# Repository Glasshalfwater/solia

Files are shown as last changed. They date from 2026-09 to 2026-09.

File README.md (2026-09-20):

# solia
### A compact tamagotchi in a rectangular form factor:

This originally started off as an idea for a birthday gift, however I realized that the timeline in which I had hoped to accomplish it was quite unrealistic. It also served as a fun way to learn KiCad (my previous projects were designed in EasyEDA Pro). The actual tamagotchi guided project took maybe 3-4 days to finish, but I wanted to make it, frankly, cooler. I decided to add a full-color TFT display, Kailh Choc keys for a more satisfying user experience, and a LiPO battery (of course along with temperature monitoring, fuse, etc.) for improved battery life. Soooo, it's been about a month and a half since I started this, said person's birthday passed a month ago, but hopefully it will be finally built soon. Another reason why I wanted to build something more complex than a basic tamagotchi (other than making it more interesting as a gift) was so it would be more fun to update later down the line. I could create "DLCs" or expansions to serve as further iterations or updates. (I had wanted to make a full color tamagotchi, so I was thinking of continuously adding new creatures with better graphics.)

### Images:

Wiring Schematic:
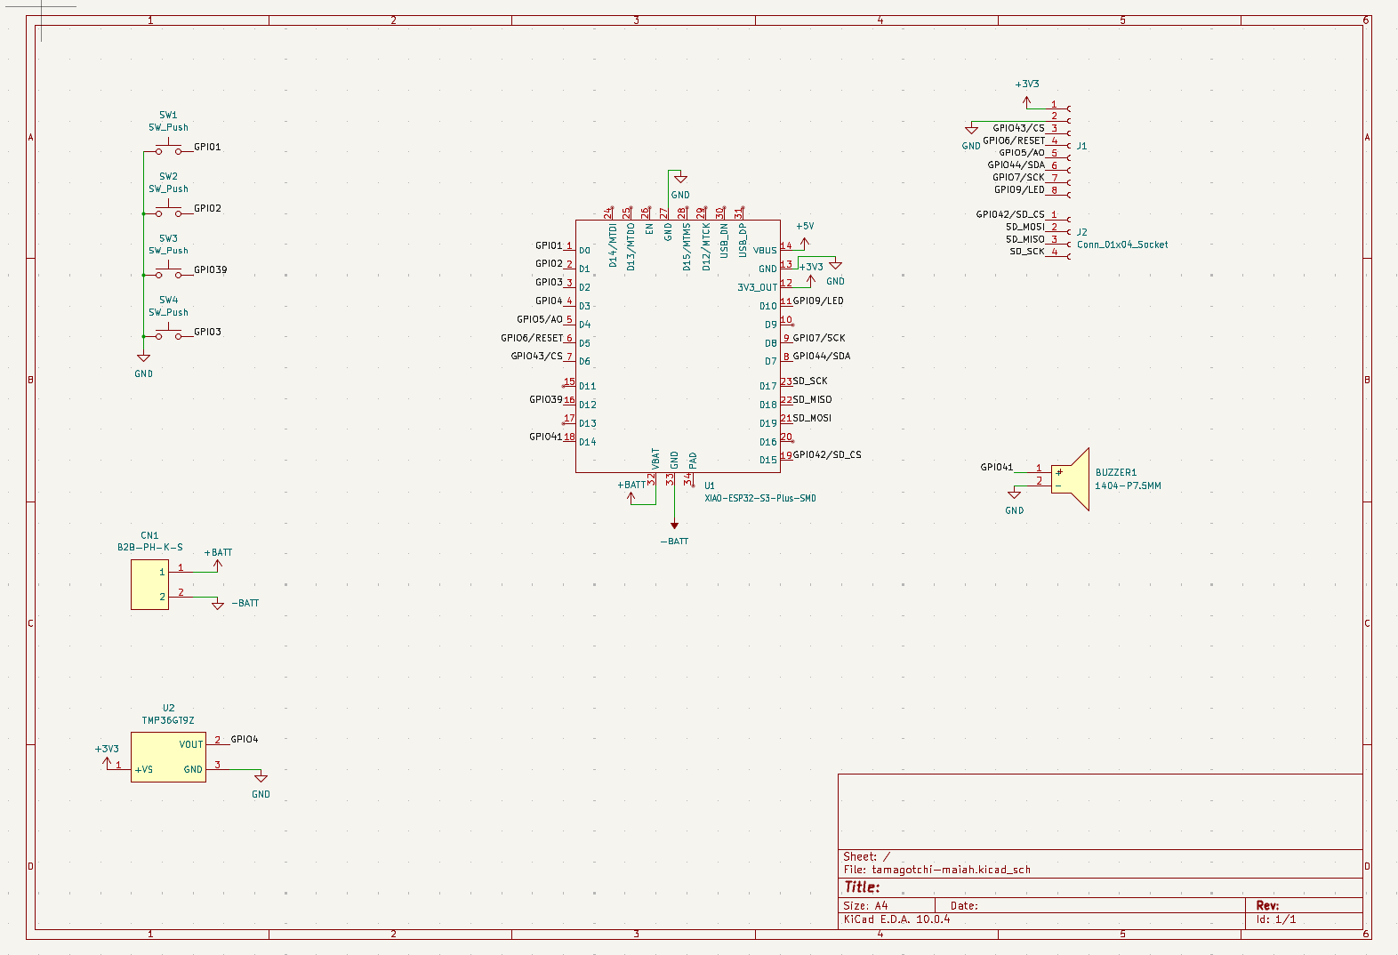
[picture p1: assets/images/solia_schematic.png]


PCB Bottom Layer:
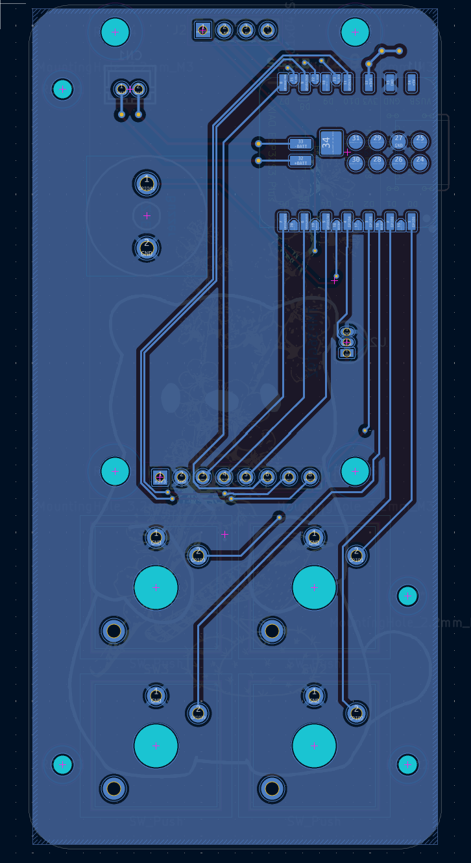
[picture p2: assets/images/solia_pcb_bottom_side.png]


PCB Top Layer:
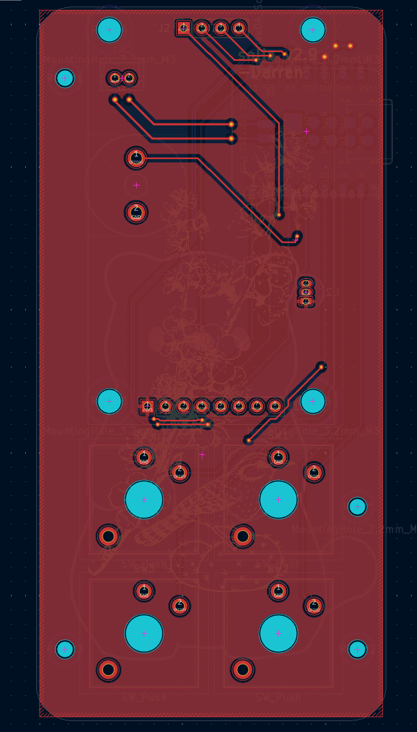
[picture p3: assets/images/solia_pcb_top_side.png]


PCB Bottom View:
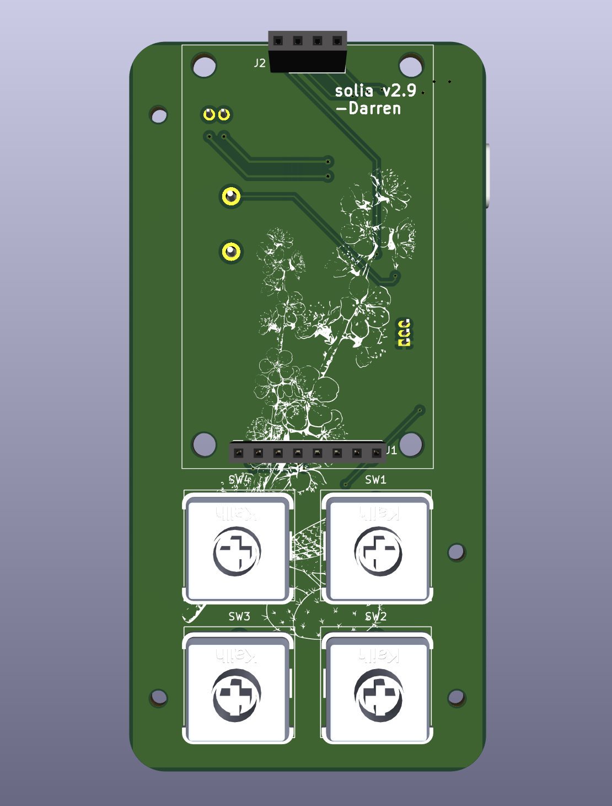
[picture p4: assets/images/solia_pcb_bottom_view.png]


PCB Top View:
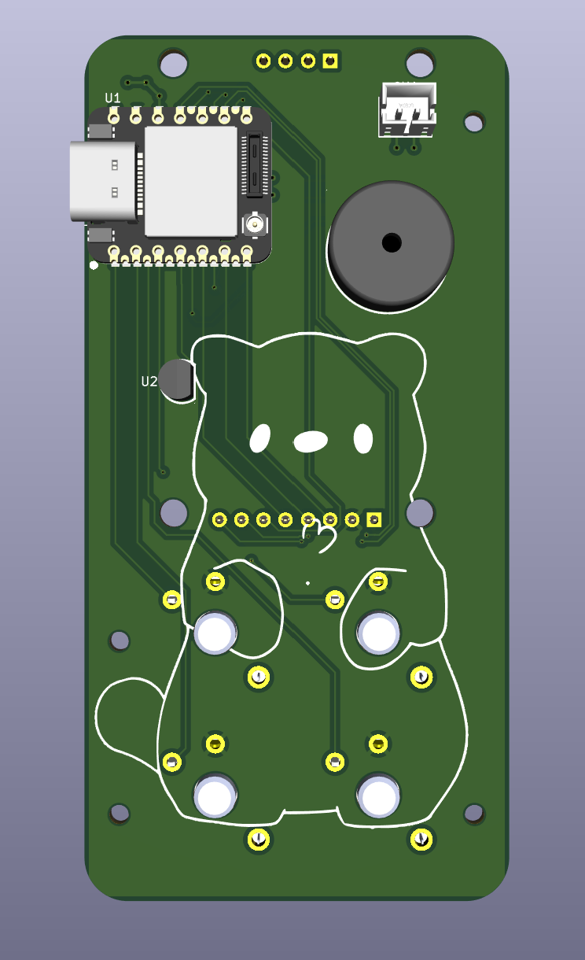
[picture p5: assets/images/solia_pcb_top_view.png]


Assembly Isometric View:
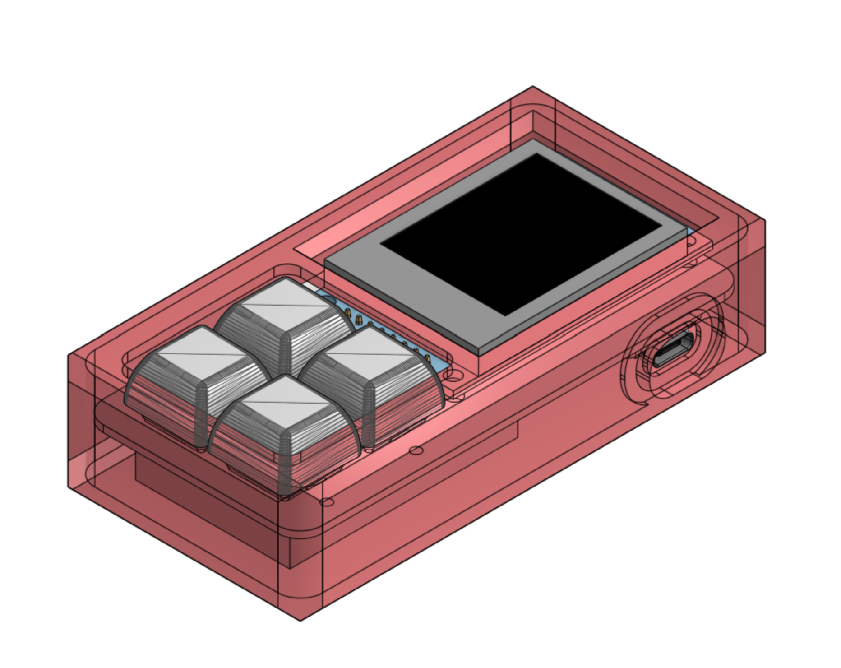
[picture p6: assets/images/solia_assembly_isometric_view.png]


Assembly Top View:
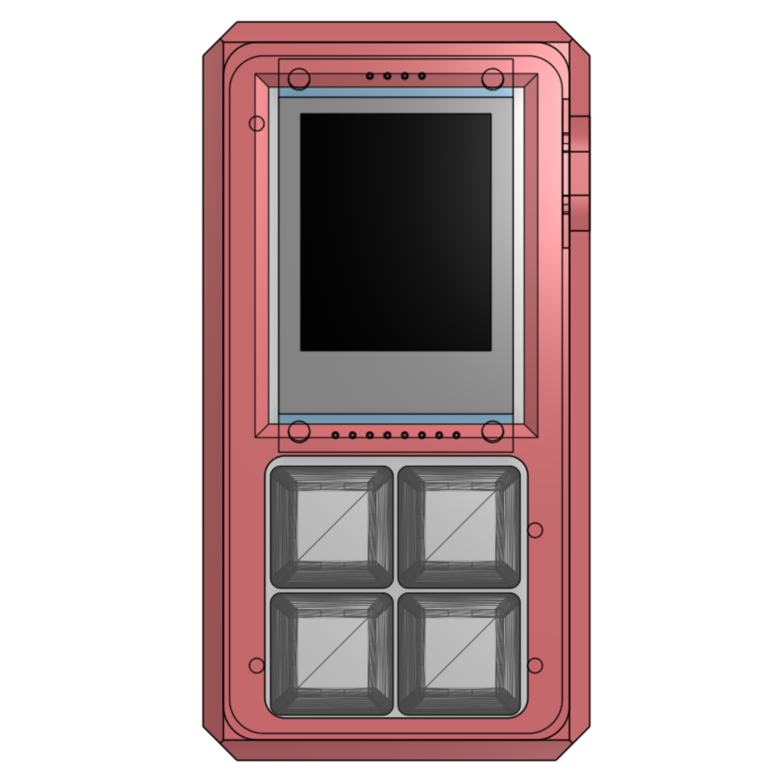
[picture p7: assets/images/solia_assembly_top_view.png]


Assembly Bottom View:
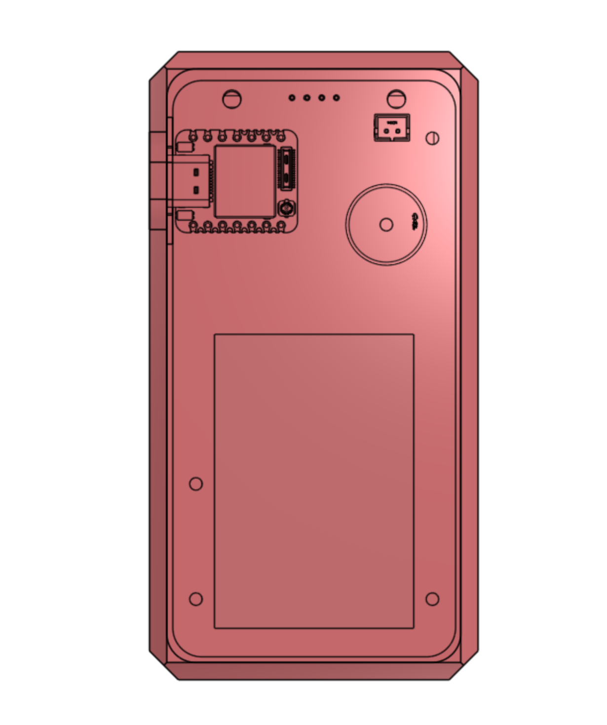
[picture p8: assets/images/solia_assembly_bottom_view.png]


Assembly Side View:
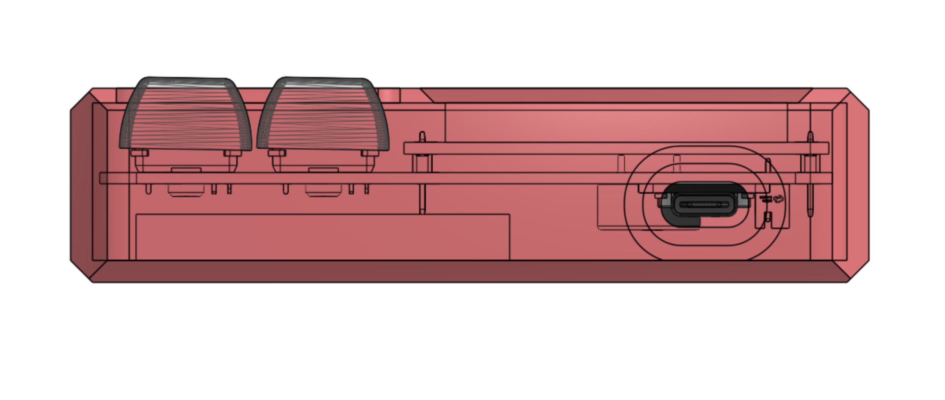
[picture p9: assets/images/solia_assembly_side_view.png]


### Onshape Link:
[Onshape Document :D](https://cvilleschools.onshape.com/documents/4abba4c252e7ebcaf10d09a4/w/88913430d3dbe53bf4207c72/e/fed4882613c54d204ad1a2a2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) 
 
### Component List:
|Name |Quantity |Price |Link |FIELD5|
|---|---|---|---|---|
|Total | N/A | ~85-90 (<65 for components but + tax and shipping and depends on how expensive your shipping is)| N/A | |
|PCB Boards | 5 (min quantity from JLCPCBD) | ~$7.00 w/ shipping | jlcpcb.com | |
|Seeed Studio XIAO ESP32 S3 Plus | 1 | $7.99 | https://www.seeedstudio.com/Seeed-Studio-XIAO-ESP32S3-Plus-p-6361.html | |
|Kailh Choc v2 Low Profile Keyboard Switches (brown switch variety)  | 10 (need 4 but whatever min quantity you can find)| $12.00 | https://www.amazon.com/KAILH-Profile-Mechanical-Keyboard-Keystem/dp/B0B463YXGQ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 | |
|Cherry MX Style Blank Keycaps 1U (white - 18 x 18 mm) | 10 (need 4) | ~$10 (for ten) | https://www.amazon.com/PATIKIL-Universal-Replacement-Accessories-Mechanical/dp/B0B5KZQ9X9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 | |
|1.8" TFT LCD Display | 1 | $14.99 | https://shillehtek.com/products/shillehtek-1-8-inch-tft-lcd-display-module-dual-side-soldering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 | |
|3.7v 1100 mAh Lithium Polymer Battery (2pin JST-PH 2.0 mm connector)| 1 | ~11 | https://www.amazon.com/EEMB-1100mAh-Battery-Rechargeable-Connector/dp/B08FD39Y5R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| |
|Temperature Sensor | 1 | $2.78 | https://www.lcsc.com/product-detail/Temperature-Sensors_ADI_TMP36GT9Z_TMP36GT9Z_C53490.html | |
|Passive Piezo-Electric Buzzer | 10 (min purchase amount for this specific model)  | $0.75 (for ten) | https://www.lcsc.com/product-detail/C49246966.html?s_z=n_q_C49246966&globalKeyword=C49246966 | |

### Setup Instructions:
Once your PCBs, case, and components arrive (list of used components), attach the XIAO via USB-C data cable to a computer capable of flashing firmware. There are multiple ways of doing so, but given that the firmware is already a .ino file, one could simply install Arduino IDE and use the built in flashing tool (just google Arduino IDE install and docs). Afterwards, assemble the PCB components, where you will likely need a hot plate for the XIAO board. Or, if you didn't screw up like me, I highly recommend editing the PCB files to include holes underneat the XIAO battery pads, so you don't have to only use solder paste and hope (if you're editing the PCB, I also recommend swapping the placement of the buzzer and the XIAO, as I didn't realize that the pins from the buzzer would hit the SD card slot attached to the screen). There is a very specific order to which the components need not to be assembled, but essentially just solder the XIAO first and confirm that nothing is shorted (multimeter, etc.), then the buzzer and temperature sensor, then the keys, and lastly the screen (as long as the XIAO is first and the screen is left to last it should be fine). Afterwards, solder the temperature fuse in between one of the battery wires (I chose positive) and the female JST connector on the board and tape the fuse onto the battery's back (adjust the postition so it slots into the hole in the case). Once you've assembled everything onto the board, place foam around the bottom of the case except for in the cutout for the fuse, and nestle the battery in. Plug the battery into the board, place everything in and seal the top of the case, and you should be good to go!
# solia_firmware

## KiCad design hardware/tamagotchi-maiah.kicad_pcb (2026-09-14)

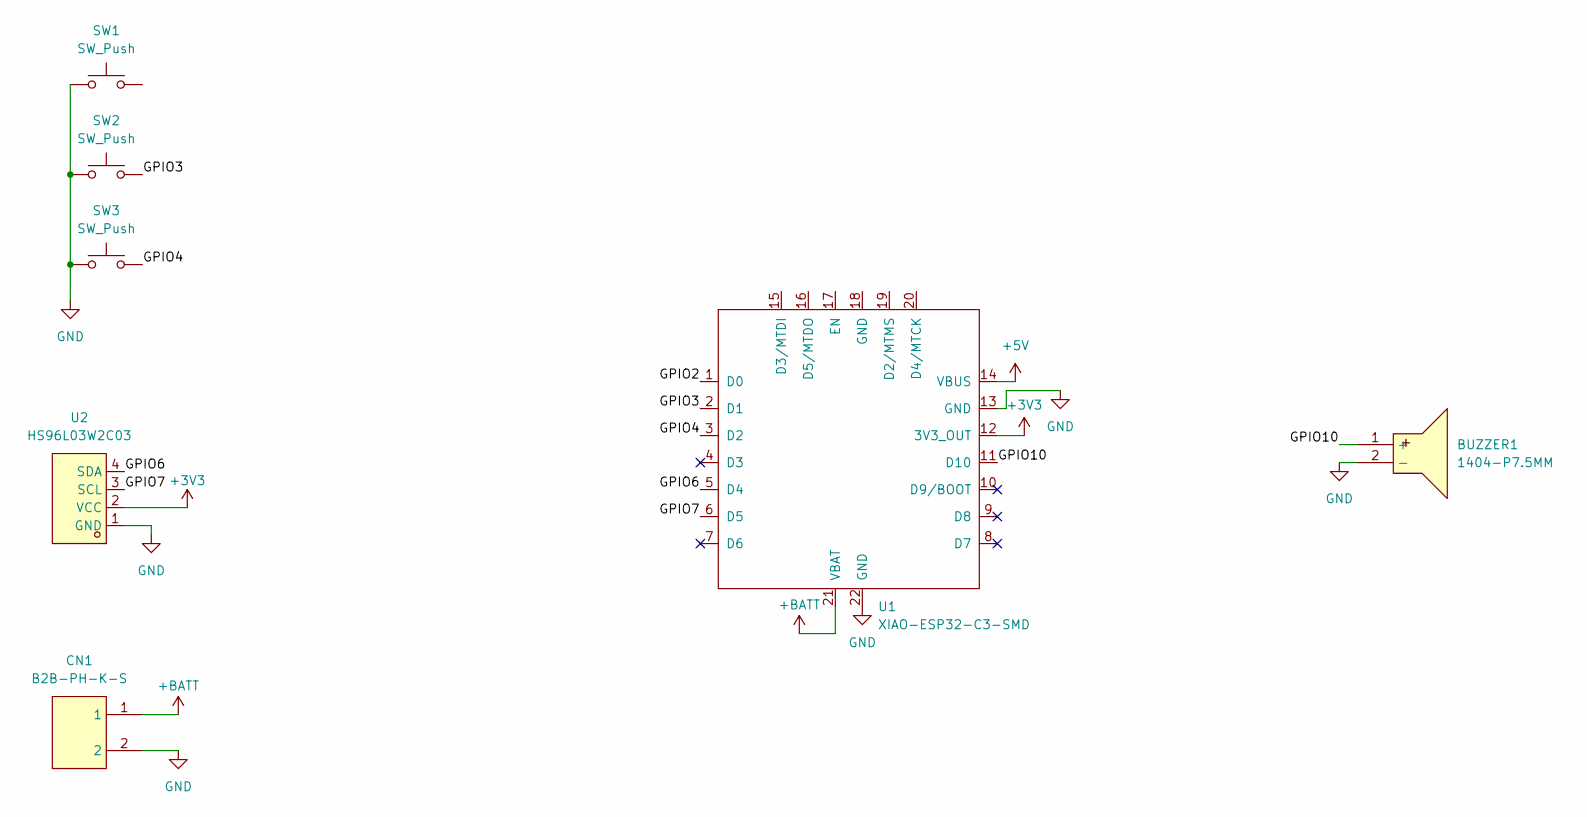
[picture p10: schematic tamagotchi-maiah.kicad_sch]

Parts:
BUZZER1: 1404-P7.5MM; BUZ-TH_BD14.0-P7.60-D0.8-L; MPN 1404-P7.5MM; LCSC Part C49246966
CN1: B2B-PH-K-S; CONN-TH_B2B-PH-K-S; MPN B2B-PH-K-S(LF)(SN); LCSC Part C131337
SW1, SW2, SW3: SW_Push; SW-TH_4P-L4.5-W4.5-P3.00-LS4.8
U1: XIAO-ESP32-C3-SMD
U2: HS96L03W2C03; OLED-TH_L27.8-W27.2-P2.54_C9900033791; MPN HS96L03W2C03; LCSC Part C5248080

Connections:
+3V3: U1.12 (3V3_OUT), U2.2 (VCC)
+5V: U1.14 (VBUS)
+BATT: CN1.1, U1.21 (VBAT)
/GPIO2: SW1.2, U1.1 (D0)
/GPIO3: SW2.2, U1.2 (D1)
/GPIO4: SW3.2, U1.3 (D2)
/GPIO6: U1.5 (D4), U2.4 (SDA)
/GPIO7: U1.6 (D5), U2.3 (SCL)
/GPIO10: BUZZER1.1 (+), U1.11 (D10)
GND: BUZZER1.2 (-), CN1.2, SW1.1, SW2.1, SW3.1, U1.13 (GND), U1.22 (GND), U2.1 (GND)

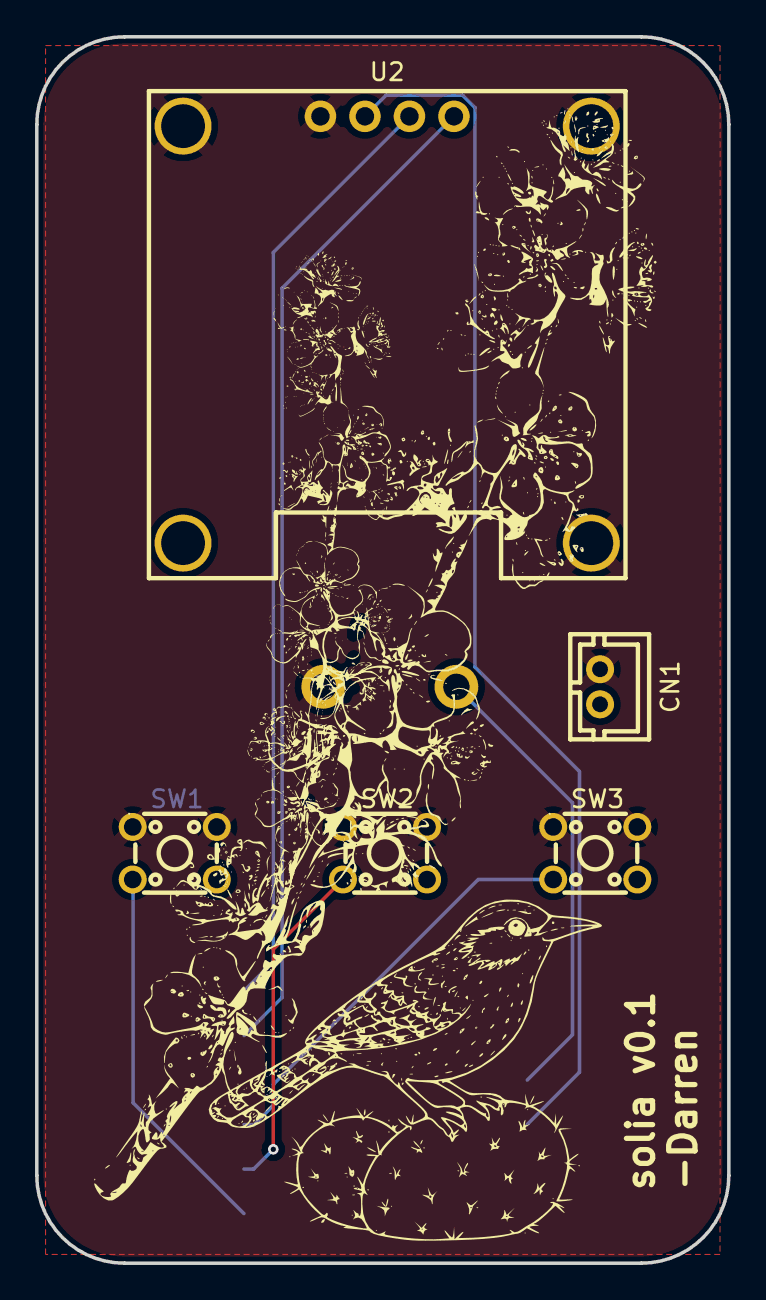
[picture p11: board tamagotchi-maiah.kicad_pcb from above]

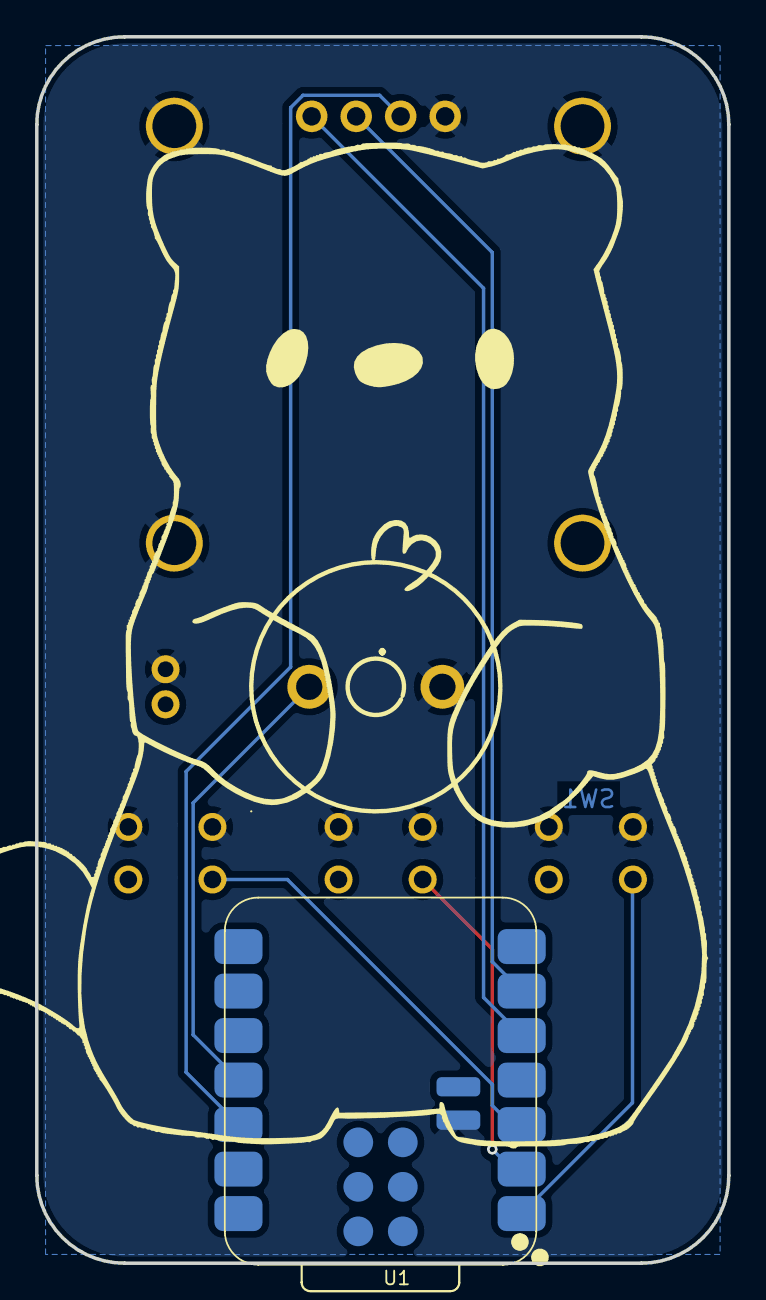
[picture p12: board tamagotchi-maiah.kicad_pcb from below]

Board: 2 copper layers, 39.5 x 70.0 mm, 8 parts (3 on the bottom side), 9 nets.

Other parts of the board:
.: LOGO; soup_on_silkscreen(50x58.2)

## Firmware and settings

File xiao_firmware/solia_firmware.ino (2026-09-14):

#include "lib\TFT_eSPI\TFT_eSPI.h"
#include "lib\TFT_eSPI\User_Setup.h" 

const int BTN_TR =  1;
const int BTN_TL = 2;
const int BTN_BL = 39;
const int BTN_BR = 3;

unsigned long last_button_press = 0;

const int TMP_SENSOR = 4;
 
const int BUZZER_PIN = 41;

TFT_eSPI tft = TFT_eSPI();

struct Pet 
{
  // Range from 0 to 100 with 0 being the lowest and 100 being the best
  int hunger;
  int happiness;
  int energy;
  unsigned long age;
};

Pet fox;

unsigned long last_update = 0;
unsigned long pet_starving = 0;
unsigned long pet_depressed = 0;
unsigned long pet_exhausted = 0;


enum Screen
{
  SCREEN_MAIN,
  SCREEN_FEED,
  SCREEN_PLAY,
  SCREEN_SLEEP,

};


Screen current_screen = SCREEN_MAIN;
Screen screen_array[] = {SCREEN_MAIN, SCREEN_FEED, SCREEN_PLAY, SCREEN_SLEEP};
int screen_index = 0;
// Example: happy face (all stats above 50)
const unsigned char PROGMEM petHappy[] = {
  0b00000000, 0b00000000,
  0b00011111, 0b11111000,
  0b00100000, 0b00000100,
  0b01000000, 0b00000010,
  0b01001100, 0b00110010,
  0b01001100, 0b00110010,
  0b01000000, 0b00000010,
  0b01000000, 0b00000010,
  0b01000100, 0b00100010,
  0b01000011, 0b11000010,
  0b01000000, 0b00000010,
  0b00100000, 0b00000100,
  0b00011111, 0b11111000,
  0b00000000, 0b00000000,
  0b00000000, 0b00000000,
  0b00000000, 0b00000000
};

// Example: sad face (any stat below 30)
const unsigned char PROGMEM petSad[] = {
  0b00000000, 0b00000000,
  0b00011111, 0b11111000,
  0b00100000, 0b00000100,
  0b01000000, 0b00000010,
  0b01001100, 0b00110010,
  0b01001100, 0b00110010,
  0b01000000, 0b00000010,
  0b01000000, 0b00000010,
  0b01000000, 0b00000010,
  0b01000011, 0b11000010,
  0b01000100, 0b00100010,
  0b00100000, 0b00000100,
  0b00011111, 0b11111000,
  0b00000000, 0b00000000,
  0b00000000, 0b00000000,
  0b00000000, 0b00000000
};

// Example: neutral face (everything else)
const unsigned char PROGMEM petNeutral[] = {
  0b00000000, 0b00000000,
  0b00011111, 0b11111000,
  0b00100000, 0b00000100,
  0b01000000, 0b00000010,
  0b01001100, 0b00110010,
  0b01001100, 0b00110010,
  0b01000000, 0b00000010,
  0b01000000, 0b00000010,
  0b01000111, 0b11100010,
  0b01000000, 0b00000010,
  0b01000000, 0b00000010,
  0b00100000, 0b00000100,
  0b00011111, 0b11111000,
  0b00000000, 0b00000000,
  0b00000000, 0b00000000,
  0b00000000, 0b00000000
};

// Example: sleeping face (closed eyes)
const unsigned char PROGMEM petSleep[] = {
  0b00000000, 0b00000000,
  0b00011111, 0b11111000,
  0b00100000, 0b00000100,
  0b01000000, 0b00000010,
  0b01001111, 0b01110010,
  0b01000000, 0b00000010,
  0b01000000, 0b00000010,
  0b01000000, 0b00000010,
  0b01000011, 0b11000010,
  0b01000000, 0b00000010,
  0b01000000, 0b00000010,
  0b00100000, 0b00000100,
  0b00011111, 0b11111000,
  0b00000000, 0b00000000,
  0b00000000, 0b00000000,
  0b00000000, 0b00000000
};

void setup() 
{
  // IO
  pinMode (BTN_TR, INPUT_PULLUP);
  pinMode (BTN_BL, INPUT_PULLUP);
  pinMode (BTN_BR, INPUT_PULLUP);

  pinMode(BUZZER_PIN, OUTPUT);

  // TFT Display
  pinMode(TFT_CS, OUTPUT);
  SPI.begin(TFT_SCLK, TFT_MOSI, TFT_CS);
  tft.init();
  tft.setRotation(0);
  tft.fillScreen(TFT_BLACK);
  
  fox.hunger = 80;
  fox.happiness = 80;
  fox.energy = 80;
  fox.age = 0;

  tft.setTextSize(1);
  tft.fillScreen(TFT_NAVY);
  tft.setTextColor(TFT_WHITE, TFT_NAVY);
  tft.setCursor(0, 20);
  tft.print("Nota OS loading...");
  delay(2000);
  tft.print("Nota OS loading...");
  delay(2000);
  tft.print("Nota OS loading...");
  delay(2000);



}

void loop() 
{ 
  check_button_io();
  update_pet(fox); 
  render();
  delay(150);   
}

void update_pet(Pet pet)
{
  if ((millis() - last_update) > 60000) // Once per minute
  {
    pet.hunger--;
    pet.happiness--;
    pet.energy--;
    pet.age++;

    // Capping values out, if stay at zero for enough time, pet dies?
    if (pet.hunger < 0)
    {
      pet.hunger = 0;
      pet_starving = millis();
    }

    if (pet.happiness < 0) 
    {
      pet.happiness = 0;
      pet_depressed = millis();
    }

    if (pet.energy < 0)
    {
      pet.energy = 0;
      pet_exhausted = millis();
    }  
  }
}

void check_button_io() 
{
  if (millis() - last_button_press < 200) return;

  // "Interaction" button
  if (digitalRead(BTN_TR) == LOW) 
  {
    switch (current_screen) 
    {
      case(SCREEN_FEED):
        fox.hunger += 15;
        if (fox.hunger > 100) fox.hunger = 100;
        break;  

      case(SCREEN_PLAY):
        fox.happiness += 10;
        if (fox.happiness > 100) fox.happiness = 100;
        break;  

      case(SCREEN_SLEEP):
        fox.energy += 30;
        if (fox.energy > 100) fox.energy = 100;
        break;
      
      case(SCREEN_MAIN):
        break;
    }
  }

  // NOTE: still requires updating based on what features they want (still need to ask), differs from tamagotchi guided tutorial because I added an extra button for switching modes
  else if (digitalRead(BTN_TL) == LOW) 
  {
    current_screen = SCREEN_PLAY;
    tone(BUZZER_PIN, 1200, 50);
    last_button_press = millis();
  }

  else if (digitalRead(BTN_BL) == LOW) 
  {
    current_screen = SCREEN_SLEEP;
    tone(BUZZER_PIN, 800, 50);
    last_button_press = millis();
  }
  else if (digitalRead(BTN_BR) == LOW)
  {
    screen_index++;
    if (screen_index >= sizeof(screen_array))
      screen_index = 0;

    switch(screen_index)
    {
      case 0:
      current_screen = screen_array[screen_index];
      tone(BUZZER_PIN, 600, 50);
      last_button_press = millis();
      break;

      case 1:
      current_screen = screen_array[screen_index];
      tone(BUZZER_PIN, 1000, 50);
      last_button_press = millis();
      break;

      case 2:
      current_screen = screen_array[screen_index];
      tone(BUZZER_PIN, 1200, 50);
      last_button_press = millis();
      break;

      case 3:
      current_screen = screen_array[screen_index];
      tone(BUZZER_PIN, 800, 50);
      last_button_press = millis();
      break;

      default:
      current_screen = screen_array[screen_index];
      tone(BUZZER_PIN, 600, 50);
      last_button_press = millis();
      break;
    }
  } 
}


// Credit: basic tone ranges Gemini
void pet_chirp() { 
  for (int frequency = 1500; frequency < 3000; frequency += 150) {
    tone(BUZZER_PIN, frequency, 15); 
    delay(10);        
  }
  
  delay(50);  
   
  for (int frequency = 2000; frequency < 3500; frequency += 150) {
    tone(BUZZER_PIN, frequency, 15); 
    delay(10); 
  }
}

// NOTE: DO NOT USE, NEEDS TO BE EDITED TO FIT ESP32 S3
void render() {
  tft.clearDisplay();

  // Choose the right sprite based on pet stats
  const unsigned char* sprite;
  if (fox.hunger < 30 || fox.happiness < 30 || fox.energy < 30) {
    sprite = petSad;
  } else if (fox.hunger > 50 && fox.happiness > 50 && fox.energy > 50) {
    sprite = petHappy;
  } else {
    sprite = petNeutral;
  }

  // Draw the pet sprite (centered horizontally, near the top)
  tft.drawBitmap(56, 2, sprite, 16, 16, SSD1306_WHITE);

  // Draw stat bars below the pet
  tft.setTextSize(1);

  tft.setCursor(0, 24);
  tft.print("HUN ");
  drawBar(24, 24, fox.hunger);

  tft.setCursor(0, 34);
  tft.print("HAP ");
  drawBar(24, 34, fox.happiness);

  tft.setCursor(0, 44);
  tft.print("ENG ");
  drawBar(24, 44, fox.energy);

  // Button labels at the bottom
  tft.setCursor(0, 56);
  tft.println("[Feed] [Play] [Sleep]");

  tft.display();
}

// Draws a stat bar: empty rectangle with a filled portion based on value (0 to 100)
void drawBar(int x, int y, int value) {
  int barWidth = 100;
  int barHeight = 6;
  int fillWidth = map(value, 0, 100, 0, barWidth);

  display.drawRect(x, y, barWidth, barHeight, SSD1306_WHITE);       // outline
  display.fillRect(x, y, fillWidth, barHeight, SSD1306_WHITE);      // filled portion
}

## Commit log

2026-07-12 initial commit, added most hardware + assets
    [tamagotchi-maiah.kicad_pcb, tamagotchi-maiah.kicad_sch]
2026-09-01 added motivation, images, and bom to readme
2026-09-01 added bom
    [BOM.csv]
2026-09-01 added more images for pcb assembly
2026-09-01 Added wiring schematic, actually fixed formatting
2026-09-14 Create solia_firmware.ino
    initial commit for solia arduino firmware
2026-09-14 fixing firmware file incorrect config
    [solia_firmware.ino]
2026-09-20 adding pcb layer images, fixed old pcb 3d view link
2026-09-20 fixed differentiation between pcb layer and pcb view
2026-09-20 fixed pcb layer image links again again
